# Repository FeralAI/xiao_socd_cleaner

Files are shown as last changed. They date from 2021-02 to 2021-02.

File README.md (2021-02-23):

# Seeeduino XIAO SOCD Cleaner

DIY SOCD cleaner module for an arcade stick, using a Seeeduino XIAO Arduino board.

## Description

The goal with this sketch is to create a standalone SOCD cleaner that runs as fast as possible with the given hardware:

* Use of Cortex®-M0+ Single Cycle IOBUS for all I/O - This allows for querying pins via direct CPU to port/register access, which is much faster than using the Arduino `digitalRead` and `digitalWrite` functions, and even faster than typical direct port manipulation! I discovered this through the [Seeeduino XIAO by Nanase](https://wiki.seeedstudio.com/Seeeduino-XIAO-by-Nanase/#use-single-cycle-iobus) page, which linked to [Sasapea's Lab](https://lab.sasapea.mydns.jp/2020/03/16/seeeduino-xiao/) for the `IOBUS.h` library.
* Caching - RAM is an afterthought when CPU cycles are on the line. Anything that can be pre-calculated (pin positions, pin values, binary offsets for compare, etc.) is stored in variables or PROGMEM prior to executing the main loop.
* Stack vs. Heap variables - Stack variables take fewer processor cycles to access.  Prioritize local variables instead of global variables.
* `Release` build optimizations - Removing the DEBUG define will exclude all benchmark and logging code, allowing for optimal performance.

### SOCD Cleaning

There are two SOCD cleaning methods to choose from, they are:

* `Neutral` - Holding SOCD will give you a neutral input on either axis.
* `Second Input Priority` - Commonly known as the `Last Win` method, this passes through the latest input for a given axis while maintaining the pressed state of the other direction for that axis. For example if you are holding left then press right, you will get a right input. If you then release and re-press left while still holding right, you will then get a left input. Finally, releasing left will give you a right input because right is still pressed. If both inputs are activated for an axis in the same input sampling window, you will receive neutral, though this is highly unlikely due to the extremely small window for sampling inputs. This is the default method for this sketch.

Each SOCD cleaning method can be modified to make the `Up` direction take priority, known as `Up Priority`. When selecting the `Neutral` method with `Up Priority` enabled, this mimics the default SOCD cleaning of the Hit Box controller. `Up Priority` can also be used with `Second Input Priority` to override the vertical axis behavior.

The 2 DIP switches in the schematic will allow selection of SOCD cleaning method (DIP 1) and Up Priority enable/disable (DIP 2). The SOCD cleaning takes from 12 cycles / 0.25μs up to 80 cycles / 1.67μs depending on the inputs and SOCD options.

## Building the XIAO SOCD Cleaner

### Pin Mapping

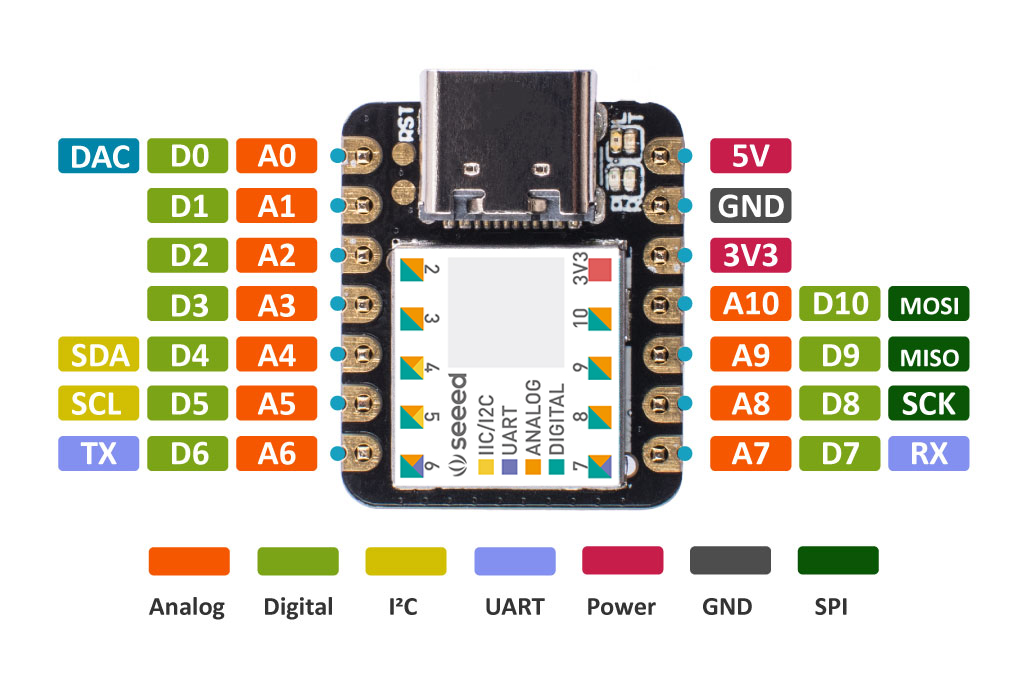
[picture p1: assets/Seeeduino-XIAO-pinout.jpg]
Seeedino XIAO pinout


The default pin mapping for this sketch is:

| Digital Pin # | PORT Pin | INPUT/OUTPUT | Direction |
| --- | --- | --- | --- |
| D0 | PA2 | INPUT | LEFT |
| D1 | PA4 | INPUT | RIGHT |
| D2 | PA10 | INPUT | DOWN |
| D3 | PA11 | INPUT | UP |
| D4 | PA8 | OUTPUT | LEFT |
| D5 | PA9 | INPUT | DIP2 |
| D6 | PB8 | INPUT | DIP1 |
| D8 | PA7 | OUTPUT | RIGHT |
| D9 | PA5 | OUTPUT | DOWN |
| D10 | PA6 | OUTPUT | UP |

### Schematic

The Seeeduino XIAO runs on 3.3v, and can be directly hooked up to encoder boards that provide 3.3v and use a common ground:

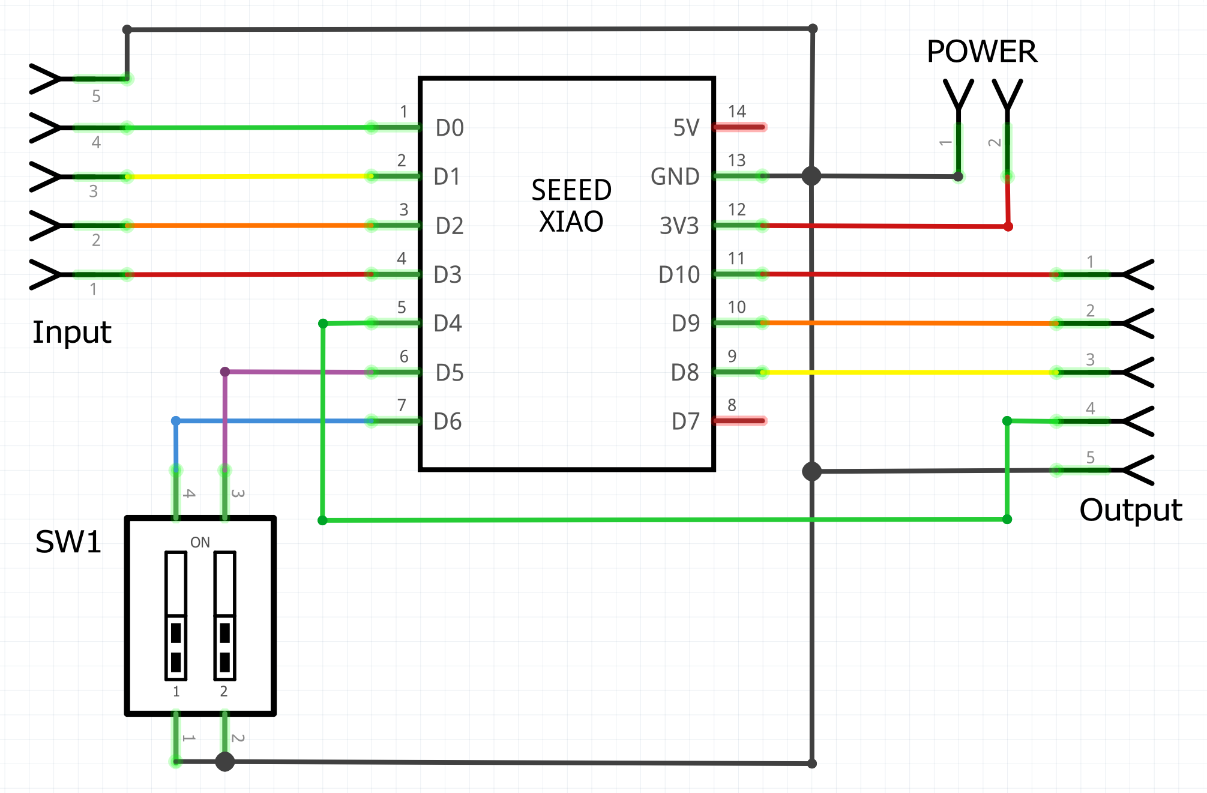
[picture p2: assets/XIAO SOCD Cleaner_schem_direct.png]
XIAO SOCD Schematic 3.3v common ground


> NOTE: The XIAO can be powered via the 5v pin instead of the 3.3v pin, however the pin logic will still run on 3.3v.

A photocoupler/optocoupler can also be used to electrically isolate the input and output circuits for better compatibility with pad hacks and retail encoders:

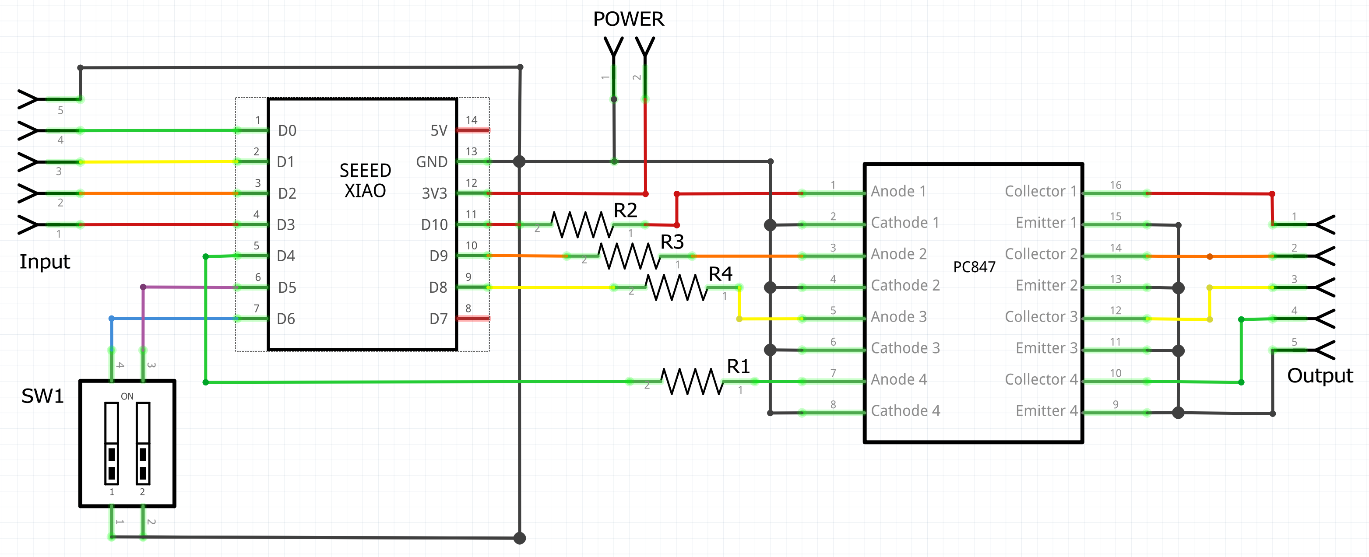
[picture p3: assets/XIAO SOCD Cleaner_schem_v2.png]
XIAO SOCD Schematic w/optocoupler


The input/output wire coloring on the schematic follows the typical Sanwa JLF wiring scheme with the 5-pin connector facing the buttons, as seen in the bottom-right corner of this image:

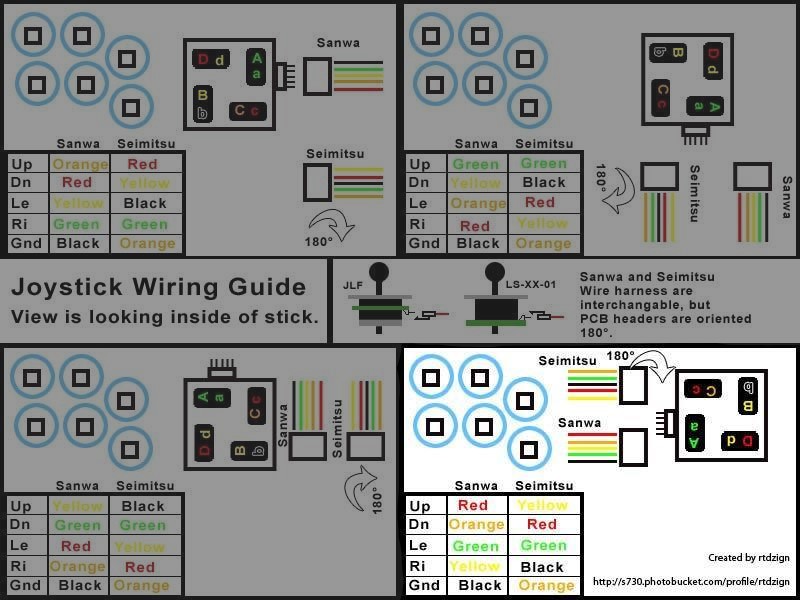
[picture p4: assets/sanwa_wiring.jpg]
Sanwa JLF wiring diagram


### Prototype

<div style="width: 100%">
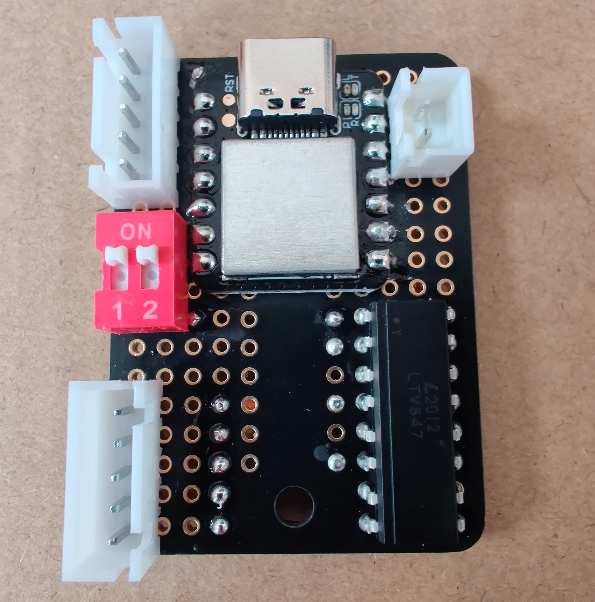
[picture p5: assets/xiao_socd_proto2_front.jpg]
XIAO SOCD Prototype Front
  
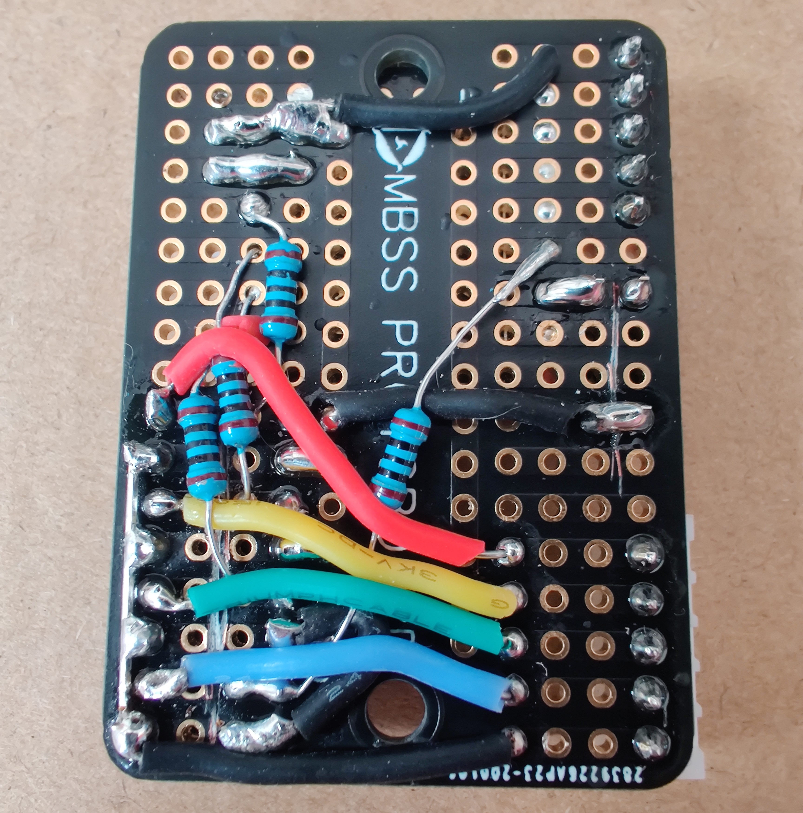
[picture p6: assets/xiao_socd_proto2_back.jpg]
XIAO SOCD Prototype Back
   
</div>

Parts used for the prototype:

* 1x Seeeduino XIAO
* 1x [Mini Perma Proto Breadboard](https://www.amazon.com/gp/product/B085WPTQ9B)
* 1x LTV847/PC847 4-channel photocoupler (rise/fall time for trigger is ~4μs)
* 4x 100Ω resistors (limits the forward voltage to the expected 1.2v for PC847 operation)
* 2x 5-pin JST-XH male connectors
* 1x 2-pin JST-XH male connector
* 1x 2-position DIP switch

### Notes

This sketch uses logic level LOW to detect an input is pressed, which is quite common for controllers and encoders. Since this prototype uses the LTV847 photocoupler, the output logic needs to be inverted to trigger a press on logic level HIGH. The `INVERT_OUTPUT_LOGIC` define is used in the sketch to, well, invert the output logic to work with the photocoupler.

### Performance

All SOCD cleaning methods take up to **2μs** for a full loop. With the **4μs** the LTV847 takes to trigger the outputs, that's about **6μs** max, or **.006ms**, of additional latency per input. I would consider that imperceptible to a human.

## TODOs

A bulk of the optimizations to be had are already done, mostly around pin and register access. There are still a few more minor optimizations to be had with the sketch and prototype:

* Evaluate logic for optimizations (inline calcs, flip boolean logic, bitwise operations, etc.)
* Use a faster photo/optocoupler, one that switches in the range of nanoseconds instead of microseconds

## Resources

* [INTRODUCTION TO SOCD AND RESOLUTIONS](https://www.hitboxarcade.com/blogs/faq/what-is-an-socd)
* [Seeeduino XIAO Wiki](https://wiki.seeedstudio.com/Seeeduino-XIAO/)
* [Seeeduino XIAO by Nanase](https://wiki.seeedstudio.com/Seeeduino-XIAO-by-Nanase/)
* [Seeeduino XIAO Schematic](https://files.seeedstudio.com/wiki/Seeeduino-XIAO/res/Seeeduino-XIAO-v1.0-SCH-191112.pdf)
* [Sasapea's Lab (IOBUS.h library)](https://lab.sasapea.mydns.jp/2020/03/16/seeeduino-xiao/)
* [LTV847 Datasheet](https://www.mouser.com/datasheet/2/239/LTV-8X7_series_201610_-1544776.pdf), [PC847 Datasheet](https://datasheet.octopart.com/PC847-Sharp-Microelectronics-datasheet-101325.pdf)

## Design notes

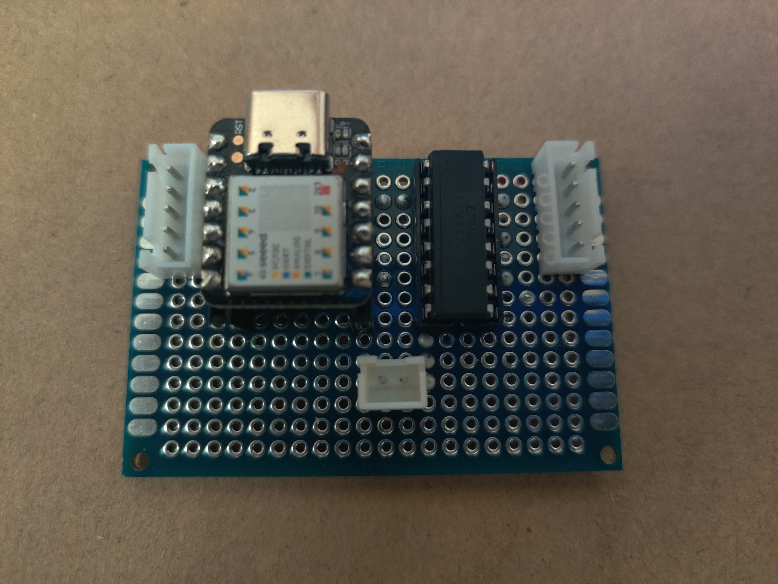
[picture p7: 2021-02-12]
assets/xiao_socd_proto1_front.jpg

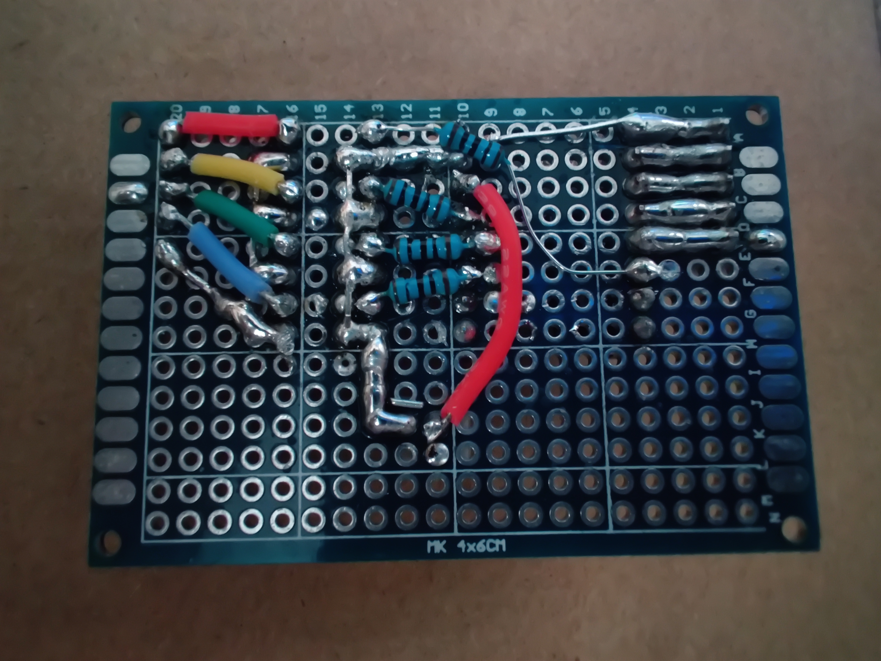
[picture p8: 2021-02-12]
assets/xiao_socd_proto1_back.jpg

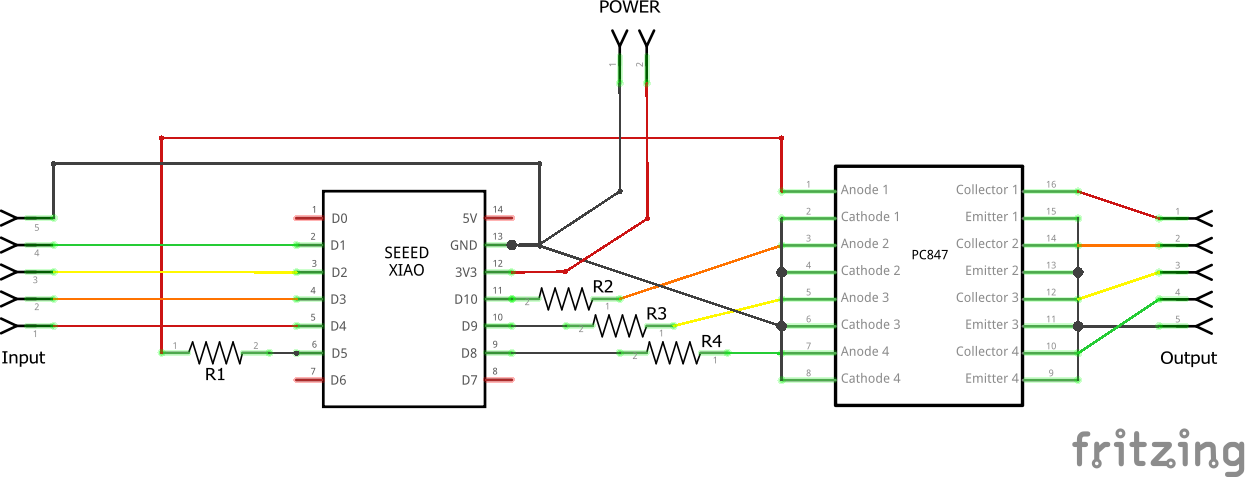
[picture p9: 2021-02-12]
assets/XIAO SOCD Cleaner_schem.png

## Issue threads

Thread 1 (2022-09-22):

Problem with input linearity in last win mode

Bertzerker, 2022-09-22:
Hey buddy,
first of all I have to thank you for the great work. It's nearly perfect in my book.
I played it for a few months now in the 8bit do arcade stick with various all the wireless adapters on all kinds of old hardware
and on PC I played a lot of training mode in Ultra Street Fighter 4. For all those it worked flawless, only the shmups did feel
like I was going a bit more diagonal than I wanted to go.

Some days ago I started playing Fightcade and specifically Vampire Savior where you have to make a lot of half circles and
you have to input it in perfect linearity, you can not go from down back to down forward without releasing back.
I think there should be a last win mode that does have a neutral in between.

Maybe it would be a good idea to use one of the analog pins with a resistor ladder on 4 pole dip switch to have more than 2 bits.
Sorry that I am bothering you, my coding is awful. I would have forked it otherwise.

Closed 2023-04-06.

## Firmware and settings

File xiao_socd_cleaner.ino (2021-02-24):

/**
 * Seeeduino XIAO SOCD Cleaner
 * 
 * The SOCD algorithms take up to 80 cycles / 1.67μs to run. This can be reduced by removing the if statements and compiling
 * for a specific SOCD method.
 * 
 * DIP 1 sets the base operating mode between Neutral (OFF) and Second Input Priority (ON).
 * DIP 2 set to ON will make Up take priority.
 * 
 */

/**
 *  User Defines
 */

// Uncomment this define to show loop time and input/output states via serial monitoring
// #define DEBUG

// Set the version of the prototype board being used - this controls the pin definitions in PINDEF.h
#define PROTOTYPE_VERSION 2

// Most controllers will use logic level LOW to trigger an input, however if you've separated your circuits with
// an optocoupler you will likely want to invert the output logic and trigger outputs with a HIGH value instead.
// Uncomment this define to invert the output logic.
// #define INVERT_OUTPUT_LOGIC

/**
 *  End User Defines
 */

#include "IODEF.h"

#define COMPARE_VALUE 65535

// Loop variables
Direction lastDirectionUD = Direction::neutral;
Direction lastDirectionLR = Direction::neutral;
bool secondInputPriority = false;
bool upPriority = false;

void configureSOCD() {
  uint32_t portA = PORT_IOBUS->Group[PORTA].IN.reg;
  uint32_t portB = PORT_IOBUS->Group[PORTB].IN.reg;

#if PROTOTYPE_VERSION == 1
  secondInputPriority = (portB & (1 << DIP1_PORT_PIN)) == 0;
  upPriority = (portB & (1 << DIP2_PORT_PIN)) == 0;
#else
  secondInputPriority = (portB & (1 << DIP1_PORT_PIN)) == 0;
  upPriority = (portA & (1 << DIP2_PORT_PIN)) == 0;
#endif
#ifdef DEBUG
  if (secondInputPriority)
    Serial.print("Using SIP SOCD cleaning");
  else
    Serial.print("Using Neutral SOCD cleaning");
  
  if (upPriority)
    Serial.println(" with Up Priority");
  else
    Serial.println();
#endif
}

void setup() {
#ifdef DEBUG
  Serial.begin(115200);
  while (!Serial);
#endif
  configurePins();
  configureSOCD();
#ifdef DEBUG
  configureTimer();
  Serial.println("Setup complete, begin SOCD algorithm");
#endif
}

void loop() {
#ifdef DEBUG
  TC5->COUNT16.COUNT.reg = 0;
#endif
  uint32_t inputValues = ~PORT_IOBUS->Group[PORTA].IN.reg;
  uint32_t outputState = 0;

  switch (inputValues & InputMasks::maskUD) {
    case InputMasks::maskUD:
      if (upPriority)
        outputState |= OutputValues::valueU;
      else if (secondInputPriority)
        outputState |= (lastDirectionUD == Direction::up) ? OutputValues::valueD : OutputValues::valueU;
      break;
    case InputMasks::maskU:
      outputState |= OutputValues::valueU;
      lastDirectionUD = Direction::up;
      break;
    case InputMasks::maskD:
      outputState |= OutputValues::valueD;
      lastDirectionUD = Direction::down;
      break;
  }

  switch (inputValues & InputMasks::maskLR) {
    case InputMasks::maskLR:
      if (secondInputPriority)
        outputState |= (lastDirectionLR == Direction::left) ? OutputValues::valueR : OutputValues::valueL;
      break;
    case InputMasks::maskL:
      outputState |= OutputValues::valueL;
      lastDirectionLR = Direction::left;
      break;
    case InputMasks::maskR:
      outputState |= OutputValues::valueR;
      lastDirectionLR = Direction::right;
      break;
  }

#ifdef INVERT_OUTPUT_LOGIC
  PORT_IOBUS->Group[0].OUTCLR.reg = (outputState ^ OutputValues::valueUDLR);
  PORT_IOBUS->Group[0].OUTSET.reg = outputState;
#else
  PORT_IOBUS->Group[0].OUTCLR.reg = outputState;
  PORT_IOBUS->Group[0].OUTSET.reg = (outputState ^ OutputValues::valueUDLR);
#endif

#ifdef DEBUG
  // Log timing
  // Takes 8 cycles to reset timer + 1 to capture during print
  Serial.println(TC5->COUNT16.COUNT.reg - 9);
  delay(100);
  // Serial.print("maskedInput: ");
  // Serial.println(maskedInput, BIN);
  // Serial.print("outputState: ");
  // Serial.println(outputState, BIN);
#endif
}

#ifdef DEBUG
void configureTimer() {
  // Enable generic clock for Timer/Counter 4 and 5
  GCLK->CLKCTRL.reg = GCLK_CLKCTRL_CLKEN | GCLK_CLKCTRL_GEN_GCLK0 | GCLK_CLKCTRL_ID(GCM_TC4_TC5);
  while (GCLK->STATUS.bit.SYNCBUSY);

  // Perform software reset
  TC5->COUNT16.CTRLA.reg = TC_CTRLA_SWRST;
  while (TC5->COUNT16.STATUS.reg & TC_STATUS_SYNCBUSY);
  while (TC5->COUNT16.CTRLA.bit.SWRST);

  // Configure TC5
  TC5->COUNT16.CTRLA.reg =
    TC_CTRLA_MODE_COUNT16 |               // Counter of 16 bits
    TC_CTRLA_WAVEGEN_MFRQ |               // Match frequency
    TC_CTRLA_PRESCALER_DIV1;              // Prescaler of 1 (no division), 1 / 48000000 = 0.0000000208333 = 20.833ns/cycle | ~1.365ms window
  TC5->COUNT16.CC[0].reg = COMPARE_VALUE; // uint16_t max value - 1
  while (TC5->COUNT16.STATUS.bit.SYNCBUSY);

  // Start counter
  TC5->COUNT16.CTRLA.reg |= TC_CTRLA_ENABLE; // Enable TC5
  while (TC5->COUNT16.STATUS.bit.SYNCBUSY);
}
#endif

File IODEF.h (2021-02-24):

/**
 * I/O definition file
 */

#ifndef __IODEF_H
#define __IODEF_H

#include "PINDEF.h"
#include "IOBUS.h"

#define digitalPinToIOPin(P) ((g_APinDescription[P].ulPort << 5) + g_APinDescription[P].ulPin)

// All pins defined on PORTA so they can be read and written in one operation
#define INPUT_IOPIN_UP     digitalPinToIOPin(INPUT_PIN_UP)
#define INPUT_IOPIN_DOWN   digitalPinToIOPin(INPUT_PIN_DOWN)
#define INPUT_IOPIN_LEFT   digitalPinToIOPin(INPUT_PIN_LEFT)
#define INPUT_IOPIN_RIGHT  digitalPinToIOPin(INPUT_PIN_RIGHT)
#define OUTPUT_IOPIN_UP    digitalPinToIOPin(OUTPUT_PIN_UP)
#define OUTPUT_IOPIN_DOWN  digitalPinToIOPin(OUTPUT_PIN_DOWN)
#define OUTPUT_IOPIN_LEFT  digitalPinToIOPin(OUTPUT_PIN_LEFT)
#define OUTPUT_IOPIN_RIGHT digitalPinToIOPin(OUTPUT_PIN_RIGHT)
#define DIP_IOPIN_1        digitalPinToIOPin(DIP1_PIN)
#define DIP_IOPIN_2        digitalPinToIOPin(DIP2_PIN)

void configurePins() {
  IOBUS::pinMode(DIP_IOPIN_1, INPUT_PULLUP);
  IOBUS::pinMode(DIP_IOPIN_2, INPUT_PULLUP);

  IOBUS::pinMode(INPUT_IOPIN_UP, INPUT_PULLUP);
  IOBUS::pinMode(INPUT_IOPIN_DOWN, INPUT_PULLUP);
  IOBUS::pinMode(INPUT_IOPIN_LEFT, INPUT_PULLUP);
  IOBUS::pinMode(INPUT_IOPIN_RIGHT, INPUT_PULLUP);

  IOBUS::pinMode(OUTPUT_IOPIN_UP, OUTPUT, true);
  IOBUS::pinMode(OUTPUT_IOPIN_DOWN, OUTPUT, true);
  IOBUS::pinMode(OUTPUT_IOPIN_LEFT, OUTPUT, true);
  IOBUS::pinMode(OUTPUT_IOPIN_RIGHT, OUTPUT, true);
  IOBUS::digitalWrite(OUTPUT_IOPIN_UP, LOW);
  IOBUS::digitalWrite(OUTPUT_IOPIN_DOWN, LOW);
  IOBUS::digitalWrite(OUTPUT_IOPIN_LEFT, LOW);
  IOBUS::digitalWrite(OUTPUT_IOPIN_RIGHT, LOW);
}

enum class Direction {
  neutral = -1,
  up      = 0,
  down    = 1,
  left    = 2,
  right   = 3,
};

// These class predefines comparison and output values, and are used to avoid on-the-fly calculations during the input cleaning process.
class InputMasks {
  public:
    // Set up input masks. Bit offsets are based on the port number, e.g. PA9 == (1 << 9).
    const static uint32_t maskD    = (1 << INPUT_PORT_PIN_DOWN);
    const static uint32_t maskL    = (1 << INPUT_PORT_PIN_LEFT);
    const static uint32_t maskR    = (1 << INPUT_PORT_PIN_RIGHT);
    const static uint32_t maskU    = (1 << INPUT_PORT_PIN_UP);
    const static uint32_t maskUD   = maskU | maskD;
    const static uint32_t maskLR   = maskL | maskR;
    const static uint32_t maskUDLR = maskU | maskD | maskL | maskR;

    const static uint32_t dip1     = (1 << DIP1_PORT_PIN);
    const static uint32_t dip2     = (1 << DIP2_PORT_PIN);
};

class OutputValues {
  public:
    // Cached output bit enable flags
    const static uint32_t valueD    = (1 << OUTPUT_PORT_PIN_DOWN);
    const static uint32_t valueL    = (1 << OUTPUT_PORT_PIN_LEFT);
    const static uint32_t valueR    = (1 << OUTPUT_PORT_PIN_RIGHT);
    const static uint32_t valueU    = (1 << OUTPUT_PORT_PIN_UP);
    const static uint32_t valueLR   = valueL | valueR;
    const static uint32_t valueUD   = valueU | valueD;
    const static uint32_t valueUDLR = valueU | valueD | valueL | valueR;
};

#endif

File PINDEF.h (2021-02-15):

/**
 * Pin definition file
 * 
 * NOTE: If the pin layout changes, the definitions in the file will need to be updated.
 */

#ifndef __PINDEF_H
#define __PINDEF_H

#ifndef PROTOTYPE_VERSION
#define PROTOTYPE_VERSION 2
#endif

// All pins defined on PORTA so they can be read and written in one operation

#if PROTOTYPE_VERSION == 1
/**
 * Prototype V1
 */
#define INPUT_PIN_UP           4 // D4/PA8
#define INPUT_PIN_DOWN         3 // D3/PA11
#define INPUT_PIN_LEFT         1 // D1/PA4
#define INPUT_PIN_RIGHT        2 // D2/PA10
#define OUTPUT_PIN_UP          5 // D5/PA9
#define OUTPUT_PIN_DOWN       10 // D10/PA6
#define OUTPUT_PIN_LEFT        8 // D8/PA7
#define OUTPUT_PIN_RIGHT       9 // D9/PA5
#define DIP1_PIN               7 // D7/PB9
#define DIP2_PIN               6 // D6/PB8

#define INPUT_PORT_PIN_UP      8 // D4/PA8
#define INPUT_PORT_PIN_DOWN   11 // D3/PA11
#define INPUT_PORT_PIN_LEFT    4 // D1/PA4
#define INPUT_PORT_PIN_RIGHT  10 // D2/PA10
#define OUTPUT_PORT_PIN_UP     9 // D5/PA9
#define OUTPUT_PORT_PIN_DOWN   6 // D10/PA6
#define OUTPUT_PORT_PIN_LEFT   7 // D8/PA7
#define OUTPUT_PORT_PIN_RIGHT  5 // D9/PA5
#define DIP1_PORT_PIN          9 // D7/PB9
#define DIP2_PORT_PIN          8 // D6/PB8

#endif

#if PROTOTYPE_VERSION >= 2
/**
 * Prototype V2
 */
#define INPUT_PIN_UP           3 // D3/PA11
#define INPUT_PIN_DOWN         2 // D2/PA10
#define INPUT_PIN_LEFT         0 // D0/PA2
#define INPUT_PIN_RIGHT        1 // D1/PA4
#define OUTPUT_PIN_UP         10 // D10/PA6
#define OUTPUT_PIN_DOWN        9 // D9/PA5
#define OUTPUT_PIN_LEFT        4 // D4/PA8
#define OUTPUT_PIN_RIGHT       8 // D8/PA7
#define DIP1_PIN               6 // D6/PB8
#define DIP2_PIN               5 // D5/PA9

#define INPUT_PORT_PIN_UP     11 // D3/PA11
#define INPUT_PORT_PIN_DOWN   10 // D2/PA10
#define INPUT_PORT_PIN_LEFT    2 // D0/P
#define INPUT_PORT_PIN_RIGHT   4 // D1/PA4
#define OUTPUT_PORT_PIN_UP     6 // D10/PA6
#define OUTPUT_PORT_PIN_DOWN   5 // D9/PA5
#define OUTPUT_PORT_PIN_LEFT   8 // D4/PA8
#define OUTPUT_PORT_PIN_RIGHT  7 // D8/PA7
#define DIP1_PORT_PIN          8 // D6/PB8
#define DIP2_PORT_PIN          9 // D5/PA9

#endif

#endif

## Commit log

2021-02-12 Add schematic
    [XIAO SOCD Cleaner.fzz]
2021-02-13 Use high resolution timer and optimize loop logic
2021-02-14 Add prototype v2 pin defs and fix SOCD cleaning
    [IODEF.h, PINDEF.h, xiao_socd_cleaner.ino]
2021-02-15 Update schematic
    [XIAO SOCD Cleaner.fzz]
2021-02-15 Implement DIP switches
2021-02-22 Update docs
    [XIAO SOCD Cleaner.fzz]
2021-02-23 Add direct connect schematic
    [XIAO SOCD Cleaner (direct).fzz]
2021-02-23 Clean up schematics
    [XIAO SOCD Cleaner (direct).fzz, XIAO SOCD Cleaner.fzz]
2021-02-23 Add note about powering the XIAO
